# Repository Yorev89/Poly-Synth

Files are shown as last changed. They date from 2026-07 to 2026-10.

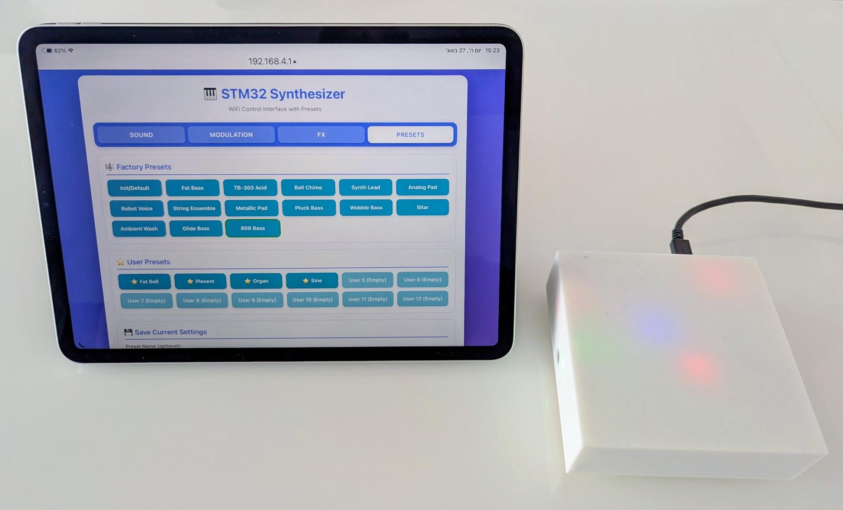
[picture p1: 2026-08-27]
docs/images/Synth and Tablet.jpg

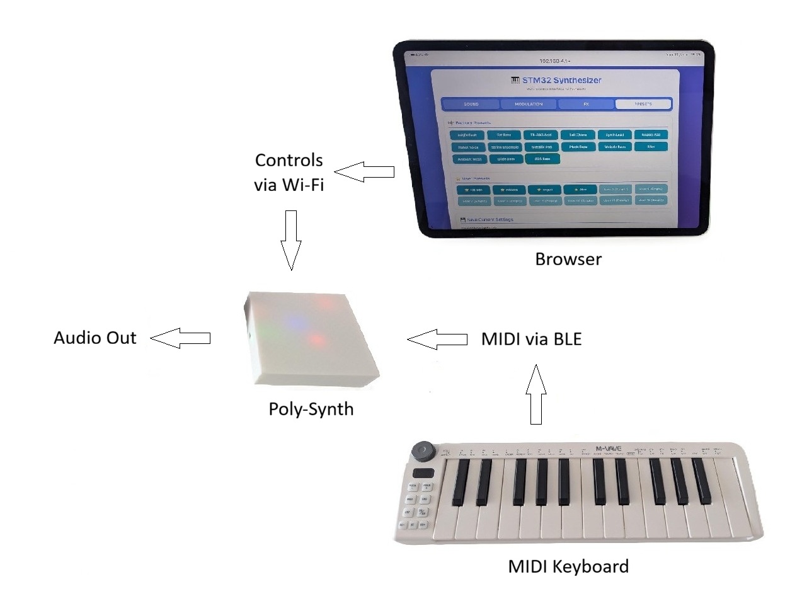
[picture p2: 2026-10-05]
docs/images/MIDI_and_Control.jpg

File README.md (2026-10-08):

# Poly-Synth — DIY Polyphonic Synthesizer
**Live site:** [yorev89.github.io/Poly-Synth](https://yorev89.github.io/Poly-Synth)

A homebrew polyphonic synthesizer built from scratch, based on a 
three-MCU architecture. This repository contains all firmware files 
and hardware resources.

## Architecture

| MCU | Role |
|---|---|
| STM32F411 | Synthesis engine, I2S audio (DIN MIDI input wired, currently disabled) |
| ESP32 #1  | Web UI, WiFi access point |
| ESP32 #2  | BLE MIDI keyboard interface |

## Features

### Synthesis Engine
- 8-voice polyphony with envelope-based voice scaling and click-free voice stealing
- Dual oscillators (Osc1 + Osc2) with 4 waveforms each: Sine, Sawtooth, Square, Triangle
- Sub oscillator: Sine or Square, selectable at -1 or -2 octaves
- White noise generator with adjustable level
- Ring modulator — continuously blendable from additive mix to full ring modulation
- Osc2 independent level and detune control (0–100 cents)
- Portamento (legato glide) with adjustable time (0–500ms), triggers on legato playing only
- Pitch bend with adjustable range

### Envelopes
- Volume ADSR: Attack 1–1000ms, Decay 1–1000ms, Sustain 0–100%, Release 1–3000ms
- Filter ADSR envelope with adjustable amount (0–100%), independently enable/disable

### Filter
- Global resonant low-pass: 2-pole (12 dB/octave) state-variable filter
- Cutoff and resonance controls; filter envelope and LFO modulation
  (sweeps from 60 Hz up to 18 kHz)

### LFO System
- Two independent LFOs
- Rate: 0.1–20 Hz each
- Waveforms: Sine, Triangle, Square, Sawtooth Up, Sawtooth Down
- Modulation targets per LFO: pitch (vibrato), filter cutoff, amplitude (tremolo), Osc2 detune

### Effects
- Stereo output: each voice is panned by pitch (low notes left, high right)
- Stereo delay (10–400ms) with time, feedback, and mix controls
- 4 delay presets (Slapback, Short, Medium, Rhythmic) plus Off; ping-pong mode
- Modulated stereo chorus

### Presets
- 15 factory presets: Init/Default, Fat Bass, TB-303 Acid, Bell Chime, Synth Lead,
  Analog Pad, Robot Voice, String Ensemble, Metallic Pad, Pluck Bass, Wobble Bass,
  Sitar, Ambient Wash, Glide Bass, 808 Bass
- 12 user-saveable preset slots (stored in ESP32 non-volatile memory)

### Connectivity & Control
- WiFi access point — no app required, connect directly from any browser
- 4-tab web interface: Sound, Modulation, FX, Presets
- BLE MIDI keyboard interface — auto-discovers BLE MIDI devices, with preferred
  device priority and automatic fallback to any BLE MIDI device
- Web-settable volume ceiling for venue or parental control, protected by a
  4-digit passcode enforced by the web controller
- MIDI keyboard volume (CC7) respects the web-set ceiling

## Firmware

| File | Board |
|---|---|
| `stm32_Synth_Engine.ino` | STM32F411 |
| `esp32_WEB_Controller.ino` | ESP32 #1  |
| `esp32_BLE.ino` | ESP32 #2  |

All three are built with the Arduino IDE.

### Required build settings for the STM32
- Core: STM32duino (STM32 MCU based boards)
- Board: Generic STM32F4 series, **Board part number: BlackPill F411CE**
  (uses the board's 25 MHz crystal for accurate tuning)
- **Tools → Optimize: Fastest (-O3)**. This is required: with the default
  "Smallest (-Os)" the synthesis loop cannot keep up with 8 voices and
  the audio distorts.

## Status
Hardware complete and verified. Firmware is playable and in active
development. Phase 2 bug fixing is complete (tuning, CPU load, clicks,
voice stealing, pitch bend, release tails, BLE MIDI parsing, volume lock);
the freed processor time went into stereo output, a modulated chorus,
ping-pong delay, and a resonant filter. Next: anti-aliased oscillators and
exponential envelope curves.

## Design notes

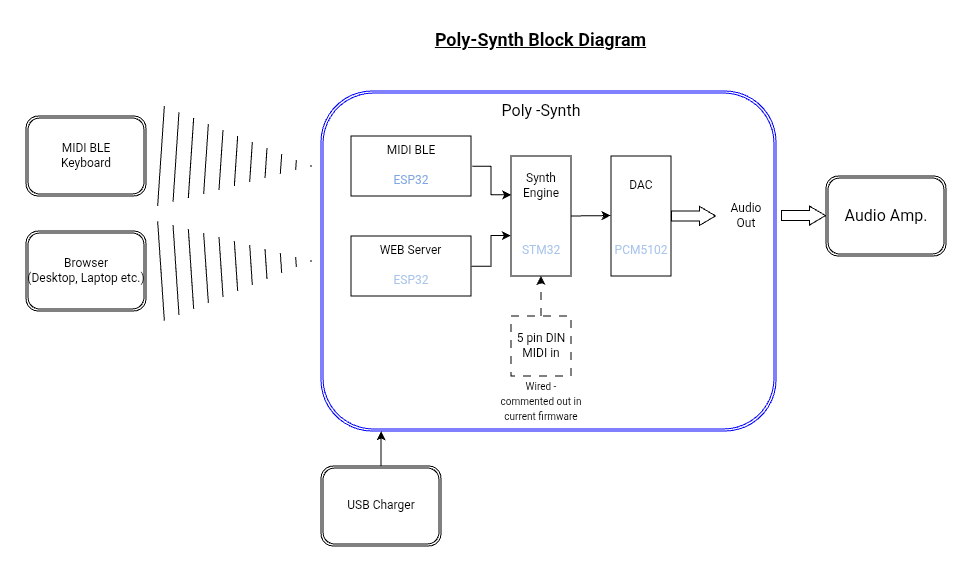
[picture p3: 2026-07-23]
Hardware/Schematics/Poly-Synth Block Diagram.png

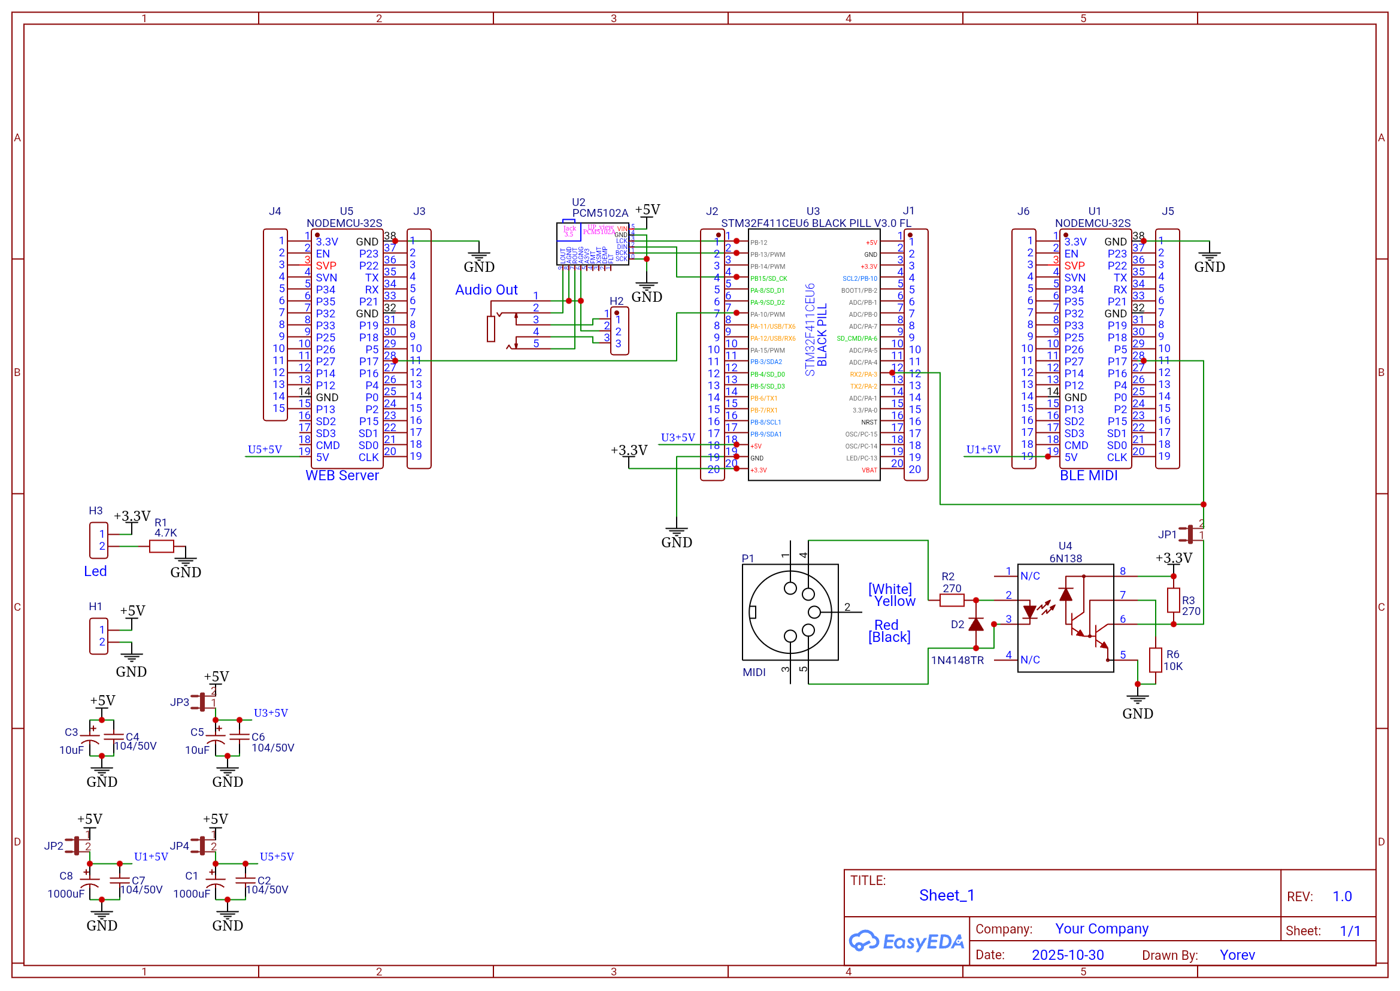
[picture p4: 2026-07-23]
Hardware/Schematics/Poly-Synth Schematic.png

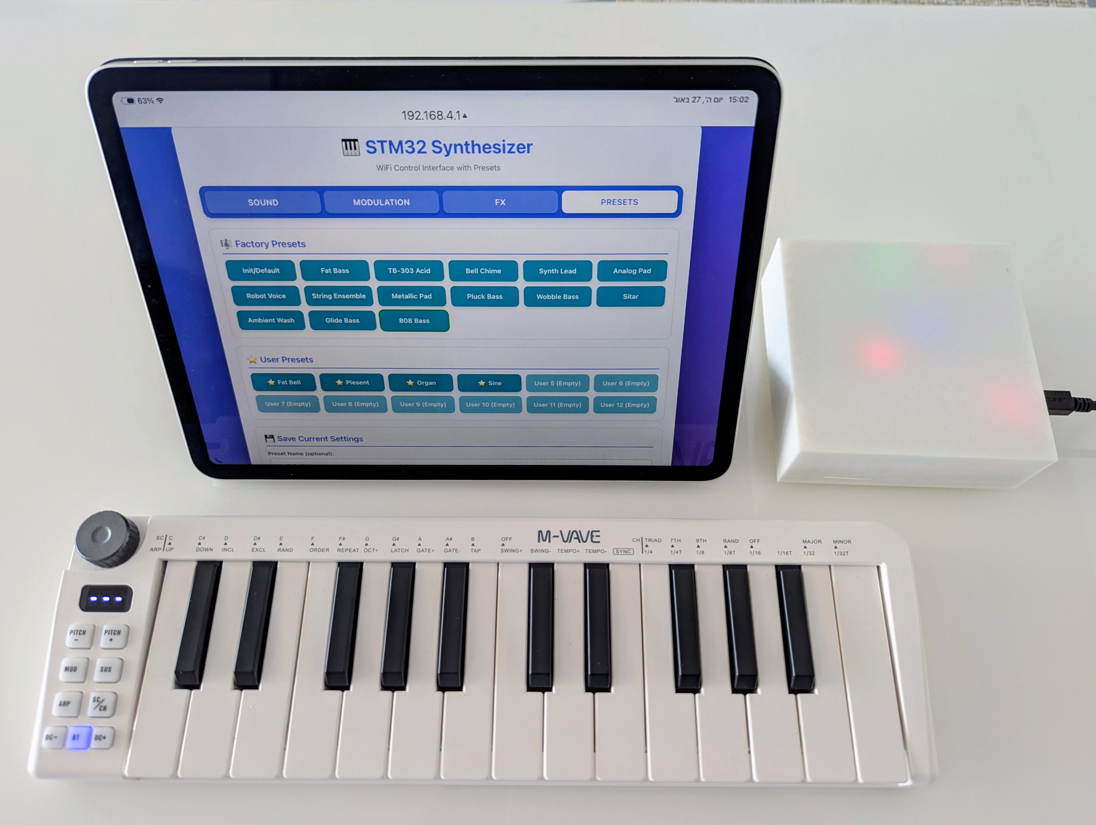
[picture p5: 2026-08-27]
docs/images/Synth.jpg

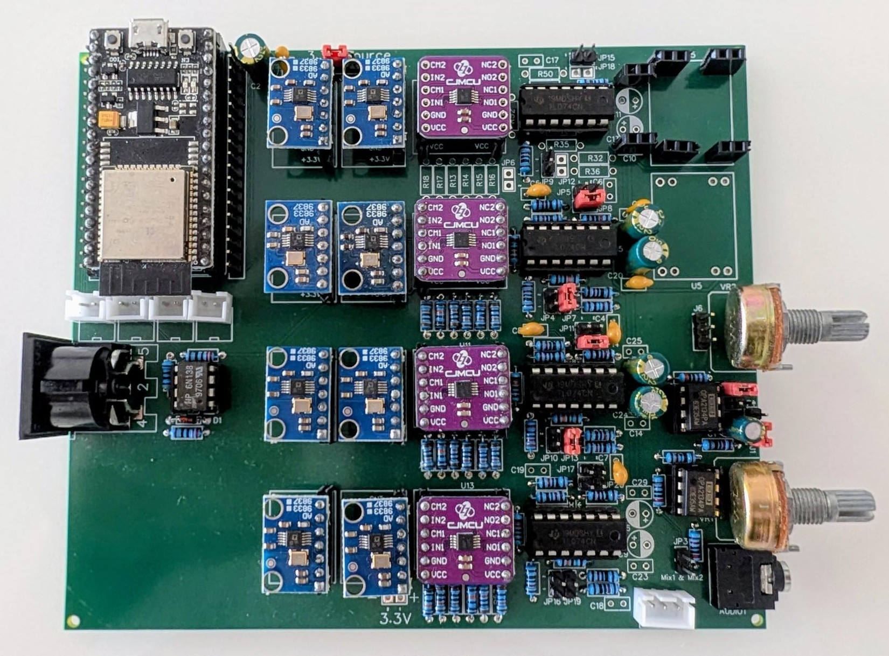
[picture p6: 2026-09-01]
docs/images/Analog Synth.jpg

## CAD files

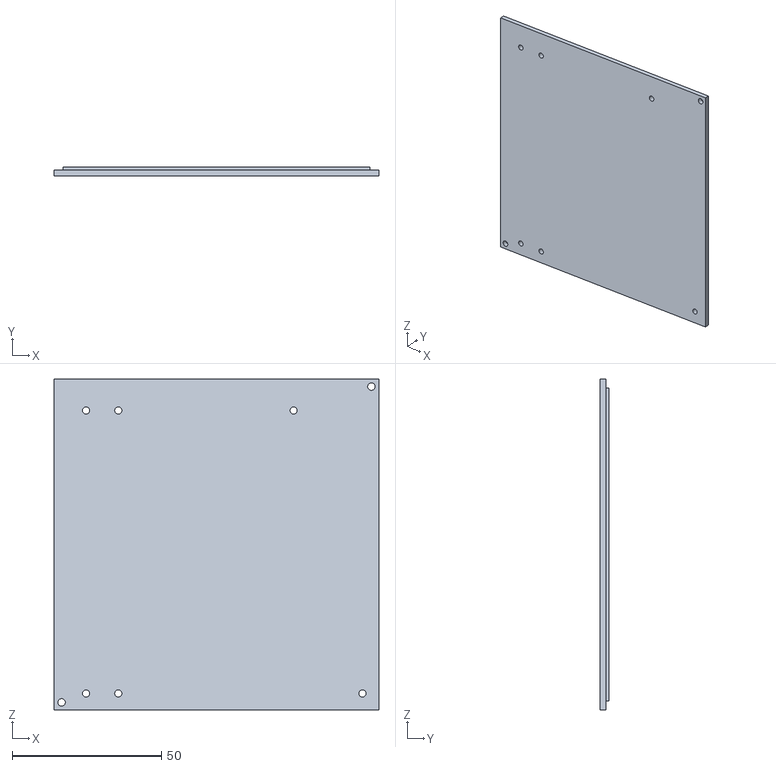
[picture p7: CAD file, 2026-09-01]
Hardware/synth-case-files/Synth Box Base.stl
109.0 x 3.00 x 111.0

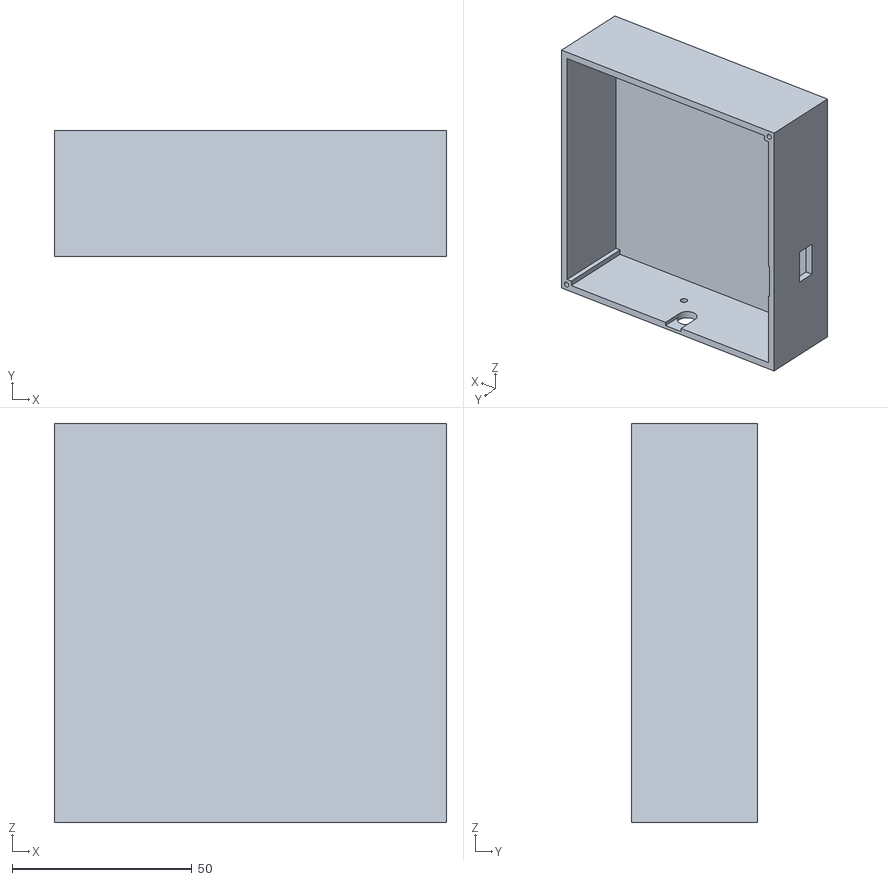
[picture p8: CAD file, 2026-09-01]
Hardware/synth-case-files/Synth Box USBC.stl
109.0 x 35.0 x 111.0

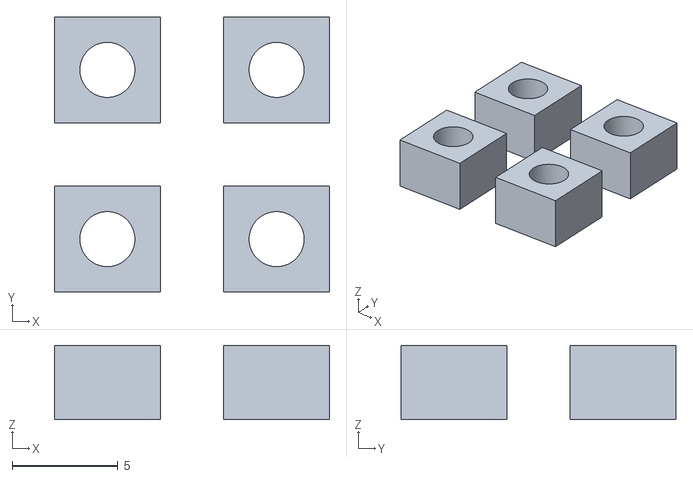
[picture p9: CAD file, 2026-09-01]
Hardware/synth-case-files/Spacers.stl
13.0 x 13.0 x 3.50

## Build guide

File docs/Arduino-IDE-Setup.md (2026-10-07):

# Arduino IDE Setup Guide

## Required Board Libraries

Install these via Arduino IDE → Board Manager:

- **ESP32** by Espressif Systems
- **STM32 MCU based boards** by STMicroelectronics

---

## STM32 Settings (F411CEU6)

**Tools menu:**

| Setting | Value |
|---|---|
| Board | STM32 MCU based boards → Generic STM32F4 Series |
| Board part number | BlackPill F411CE |
| Upload method | STM32CubeProgrammer (DFU) |
| U(S)ART support | Enabled (generic Serial) |
| USB support | CDC (generic Serial supersede U(S)ART) |
| Optimize | Fastest (-O3) |
| Port | Whichever COM/dev port appears when connected |

**Entering DFU mode (USB upload, no ST-Link):**

1. Hold BOOT0 button
2. Press and release RESET
3. Release BOOT0
4. Upload from IDE

> If using an ST-Link, no button sequence needed — connect and upload via SWD.

---

## ESP32 Settings (NodeMCU-32S)

**Tools menu:**

| Setting | Value |
|---|---|
| Board | ESP32 Arduino → ESP32 Dev Module |
| Upload Speed | 921600 |
| CPU Frequency | 240MHz (WiFi/BT) |
| Flash Frequency | 80MHz |
| Flash Mode | QIO |
| Flash Size | 4MB (32Mb) |
| Partition Scheme | Default 4MB with spiffs |
| Core Debug Level | None |
| PSRAM | Disabled |
| Port | Whichever COM/dev port appears when connected |

> NodeMCU-32S has auto-reset built in — no button sequence needed, just hit Upload.

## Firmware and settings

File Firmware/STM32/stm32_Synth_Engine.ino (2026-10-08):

/*
 * STM32F411CEU6 Polyphonic Synthesizer - Poly-Synth synthesis engine
 * https://github.com/Yorev89/Poly-Synth
 *
 * Features:
 * - 8-voice polyphony with adaptive voice scaling and click-free voice stealing
 * - Dual oscillators + sub oscillator (4 waveforms each), ring modulator
 * - ADSR amplitude envelope per voice + filter envelope
 * - Global resonant 2-pole (12 dB/oct) state-variable low-pass, LFO + envelope
 * - Stereo voice panning by pitch; delay (10-400 ms, presets, ping-pong mode);
 *   modulated stereo chorus (10 ms +/- 2.5 ms, 0.5 Hz, L/R 90 deg apart)
 * - 2x LFO (pitch, filter, amplitude, detune modulation)
 * - 15 factory presets + 12 user preset slots (stored on ESP32 #1)
 * - I2S sample rate computed at boot; tuning compensated to the real rate
 * - Voice gain scaled by summed envelope levels (smooth chords and release tails)
 *
 * Hardware:
 * - STM32F411CEU6 (WeAct Black Pill V3.1), 25 MHz HSE, 96 MHz core
 * - PCM5102A DAC via I2S (PB12=WS, PB13=BCK, PB15=DIN)
 * - ESP32 #1 (web controller, Wi-Fi AP) -> UART RX on PA10 (WebSerial)
 * - ESP32 #2 (BLE MIDI receiver)        -> UART RX on PA3, TX on PA2 (ESP32Serial)
 * - 5-pin DIN MIDI input: wired, but disabled - its UART pin (PA10) now serves ESP32 #1
 *
 * MIDI flow:
 * BLE MIDI keyboard -> ESP32 #2 -> UART -> STM32
 * Commands: NOTE,<note>,<velocity> | NOTEOFF,<note> | PITCHBEND,<lsb>,<msb> | CC,<num>,<val>
 *
 * Build: Arduino IDE, STM32 core, Board part number: BlackPill F411CE
 *        (uses the 25 MHz crystal), Tools -> Optimize -> Fastest (-O3) REQUIRED
 * (with the default -Os the render loop misses its deadline and audio distorts)
 */

#include <Arduino.h>

#define TARGET_SAMPLE_RATE 44100.0f
// Real output sample rate, set by configureI2SClock() at the start of setup().
// All pitch/time calculations use this value, so tuning stays correct even if
// the clock tree can't produce exactly 44100 Hz.
float SAMPLE_RATE = TARGET_SAMPLE_RATE;
uint16_t i2sPrescaler = 0;  // Value for SPI2->I2SPR: I2SDIV | (ODD << 8)
// DIAGNOSTICS (temporary): render timing
uint32_t diagMaxRenderCycles = 0;
uint32_t diagMissedBuffers = 0;
volatile uint32_t diagHalfStamp = 0, diagFullStamp = 0;  // DWT time of DMA interrupt
uint32_t diagMaxLatencyCycles = 0;  // interrupt -> render finished
uint32_t diagLateBuffers = 0;       // renders that finished after their deadline
#define AUDIO_BUFFER_SIZE 512
#define WAVE_TABLE_SIZE 256
#define MAX_VOICES 8
#define MIDI_BAUD_RATE 31250

#define MIDI_NOTE_OFF 0x80
#define MIDI_NOTE_ON 0x90
#define MIDI_CONTROL_CHANGE 0xB0
#define MIDI_PITCH_BEND 0xE0

enum WaveType { WAVE_SINE, WAVE_SAW, WAVE_SQUARE, WAVE_TRIANGLE };
enum EnvStage { ENV_IDLE, ENV_ATTACK, ENV_DECAY, ENV_SUSTAIN, ENV_RELEASE };

int16_t sineTable[WAVE_TABLE_SIZE];
int16_t sawTable[WAVE_TABLE_SIZE];
int16_t squareTable[WAVE_TABLE_SIZE];
int16_t triangleTable[WAVE_TABLE_SIZE];

int16_t audioBuffer[AUDIO_BUFFER_SIZE];
DMA_HandleTypeDef hdma_spi2_tx;
volatile uint32_t halfComplete = 0;
volatile uint32_t fullComplete = 0;

// HardwareSerial MidiSerial(PA10, PA9);  // COMMENTED OUT - PA10 used by WebSerial
HardwareSerial ESP32Serial(PA3, PA2);
HardwareSerial WebSerial(PA10, PA9);  // ESP32 #1 Web Control
uint8_t midiChannel = 0xFF;

struct Oscillator {
  uint32_t phase;
  uint32_t phaseInc;
  WaveType waveType;
  float detune;
};

struct Envelope {
  EnvStage stage;
  float level;
  float attackRate;
  float decayRate;
  float sustainLevel;
  float releaseRate;
};

struct Voice {
  bool active;
  uint8_t note;
  Oscillator osc1;
  Oscillator osc2;
  Oscillator sub;
  Envelope env;
  Envelope filterEnv;
  float velocity;
  float panL, panR;          // Stereo gains, set from the note's pitch at note-on
  unsigned long noteOnTime;
  // Portamento (cheap phaseInc-based approach)
  bool portaActive;
  float portaRate;           // Multiply phaseInc by this each sample
  uint32_t portaTargetInc1;  // Target phaseInc for osc1
  uint32_t portaTargetInc2;  // Target phaseInc for osc2
  uint32_t portaTargetSubInc;// Target phaseInc for sub
  // Float accumulators - avoid uint32_t truncation during slow glides
  float portaInc1f;
  float portaInc2f;
  float portaSubIncf;
};

Voice voices[MAX_VOICES];

// Global resonant low-pass filter: 2-pole (12 dB/octave) state-variable filter
// in the trapezoidal / zero-delay-feedback form (Andrew Simper, Cytomic),
// which stays stable and in tune up to the highest cutoff settings.
// (Replaces the one-pole 6 dB/octave filter that had no resonance.)
struct GlobalFilter {
  float a1, a2, a3;      // coefficients for the current cutoff / resonance
  float ic1L, ic2L;      // left channel integrator states
  float ic1R, ic2R;      // right channel integrator states
} globalFilter;
float filterResonance = 0.0f;  // 0..1 (0 = flat Butterworth, 1 = Q 10, strong squelch)

// ==================== SYNTH PARAMETERS ====================

float osc1Detune = 0.0;
float osc2Detune = 7.0;
float osc2Level = 0.7;  // Adjustable via WiFi
WaveType osc1Wave = WAVE_SAW;
WaveType osc2Wave = WAVE_SAW;

// Sub oscillator
float subLevel = 0.0;      // 0-100% (default OFF)
int subOctave = 1;         // 1 = -1 octave, 2 = -2 octaves
WaveType subWave = WAVE_SINE;  // SINE or SQUARE (classic choices)

// Ring Modulator
float ringModAmount = 0.0;  // 0-100% (0=additive, 100=full ring mod)

// Portamento
bool portamentoEnabled = false;
float portamentoTime = 0.1;   // 0-2 seconds
float lastPlayedFreq = 0.0;   // Source frequency for glide

// Noise generator
float noiseLevel = 0.0;    // 0-100% (default OFF)

// ADSR - now adjustable via WiFi!
float attackTime = 0.005;    // 1-1000 ms
float decayTime = 0.05;      // 1-1000 ms
float sustainLevel = 0.7;    // 0-100%
float releaseTime = 0.05;    // 1-3000 ms

// Filter Envelope
bool filterEnvEnabled = false;
float filterEnvAttack = 0.005;    // 1-1000 ms
float filterEnvDecay = 0.05;      // 1-1000 ms
float filterEnvSustain = 0.5;     // 0-100%
float filterEnvRelease = 0.05;    // 1-3000 ms
float filterEnvAmount = 0.5;      // 0-100% - how much envelope affects filter

float filterCutoff = 5000.0;

// LFO System
enum LFOWaveType { LFO_SINE, LFO_TRIANGLE, LFO_SQUARE, LFO_SAW_UP, LFO_SAW_DOWN };
struct LFO {
  uint32_t phase;
  uint32_t phaseInc;
  LFOWaveType waveType;
  float rate;  // Hz (0.1 - 20 Hz)
  
  // Modulation depths (0.0 - 1.0)
  float pitchDepth;      // Vibrato (0-100 cents)
  float filterDepth;     // Filter mod (0-3000 Hz)
  float ampDepth;        // Tremolo
  float osc2DetuneDepth; // Osc2 detune mod (0-50 cents)
} lfo1, lfo2;  // Two independent LFOs!

bool lfo1Enabled = false;
bool lfo2Enabled = false;

// 400 ms at 44.1 kHz, stored as int16 (same RAM as the old 200 ms float buffers).
// Range +/-2.0 maps to the full int16 range (DELAY_SCALE = 16384).
#define DELAY_BUFFER_SIZE 17640
#define DELAY_SCALE 16384.0f
int16_t delayBufferL[DELAY_BUFFER_SIZE];
int16_t delayBufferR[DELAY_BUFFER_SIZE];
int delayWritePos = 0;
float delayTime = 0.0;       // 0 seconds (off)
float delayFeedback = 0.0;
float delayMix = 0.0;
int delayPreset = 0;
bool delayPingPong = false;  // ping-pong mode: echoes alternate left / right
int feedbackPreset = 1;


#define CHORUS_BUFFER_SIZE 1323
float chorusBufferL[CHORUS_BUFFER_SIZE];
float chorusBufferR[CHORUS_BUFFER_SIZE];
int chorusWritePos = 0;
float chorusMix = 0.6;
bool chorusEnabled = false;

// Modulated stereo chorus: one delay line per channel, read at a delay that a
// slow LFO sweeps around CHORUS_BASE_MS; left and right LFOs are a quarter
// cycle apart for width. (Replaces the old static 4-tap comb filter.)
#define CHORUS_BASE_MS   10.0f   // centre delay
#define CHORUS_DEPTH_MS   2.5f   // sweep +/- this much
#define CHORUS_RATE_HZ    0.5f   // LFO rate
float chorusLfoPhase = 0.0f;     // 0..1

float masterVolume = 1.0;  // Maximum (was 0.7 = +43% gain)
float volumeCeiling = 1.0;  // 0-1: Web-locked maximum volume (parent control)
float keyboardVolumeCC = 1.0;  // 0-1: MIDI keyboard's volume knob position
float pitchBendAmount = 0.0;
float pitchBendRange = 2.0;

// ==========================================================

const char* getWaveName(WaveType wave) {
  switch(wave) {
    case WAVE_SINE: return "SINE";
    case WAVE_SAW: return "SAW";
    case WAVE_SQUARE: return "SQUARE";
    case WAVE_TRIANGLE: return "TRIANGLE";
    default: return "UNKNOWN";
  }
}

// ==================== I2S CLOCK CONFIGURATION ====================
// Searches PLLI2S M/N/R and I2SDIV/ODD for the rate closest to targetRate,
// programs PLLI2S, and returns the sample rate actually produced.
// I2S mode: 16-bit data, 16-bit channel (32 bits per stereo frame), no MCLK:
//   Fs = I2SCLK / (32 * (2*I2SDIV + ODD))
// Limits (RM0383 / F411 datasheet): PLL input 0.95-2.1 MHz, VCO 100-432 MHz,
// I2SCLK <= 192 MHz, N 50-432, R 2-7, I2SDIV 2-255.
float configureI2SClock(float targetRate) {
  bool useHSE = (RCC->PLLCFGR & RCC_PLLCFGR_PLLSRC) != 0;  // PLLI2S shares the PLL source
  float srcHz = useHSE ? (float)HSE_VALUE : (float)HSI_VALUE;

#ifdef RCC_PLLI2SCFGR_PLLI2SM
  const uint32_t mMin = 2, mMax = 63;   // F411: PLLI2S has its own input divider
#else
  uint32_t mFixed = RCC->PLLCFGR & RCC_PLLCFGR_PLLM;  // otherwise shares main PLLM
  const uint32_t mMin = mFixed, mMax = mFixed;
#endif

  float bestErr = 1e12f, bestRate = 0.0f;
  uint32_t bestM = 0, bestN = 0, bestR = 0, bestK = 0;

  for (uint32_t m = mMin; m <= mMax; m++) {
    float pllIn = srcHz / m;
    if (pllIn < 0.95e6f || pllIn > 2.1e6f) continue;
    for (uint32_t n = 50; n <= 432; n++) {
      float vco = pllIn * n;
      if (vco < 100e6f || vco > 432e6f) continue;
      for (uint32_t r = 2; r <= 7; r++) {
        float i2sclk = vco / r;
        if (i2sclk > 192e6f) continue;
        uint32_t k = (uint32_t)(i2sclk / (32.0f * targetRate) + 0.5f);  // k = 2*DIV + ODD
        if (k < 4 || k > 511) continue;
        float rate = i2sclk / (32.0f * k);
        float err = fabsf(rate - targetRate);
        if (err < bestErr) {
          bestErr = err; bestRate = rate;
          bestM = m; bestN = n; bestR = r; bestK = k;
        }
      }
    }
  }

  // Program PLLI2S (must be off while changing it)
  RCC->CR &= ~RCC_CR_PLLI2SON;
  while (RCC->CR & RCC_CR_PLLI2SRDY);
  uint32_t cfg = (bestN << RCC_PLLI2SCFGR_PLLI2SN_Pos) |
                 (bestR << RCC_PLLI2SCFGR_PLLI2SR_Pos);
#ifdef RCC_PLLI2SCFGR_PLLI2SM
  cfg |= (bestM << RCC_PLLI2SCFGR_PLLI2SM_Pos);
#endif
  RCC->PLLI2SCFGR = cfg;
  RCC->CR |= RCC_CR_PLLI2SON;
  while (!(RCC->CR & RCC_CR_PLLI2SRDY));

  i2sPrescaler = (uint16_t)((bestK >> 1) | ((bestK & 1) << 8));

  Serial.print("I2S clock: src=");   Serial.print(useHSE ? "HSE " : "HSI ");
  Serial.print(srcHz / 1e6f, 3);     Serial.print(" MHz  M=");  Serial.print(bestM);
  Serial.print(" N=");  Serial.print(bestN);
  Serial.print(" R=");  Serial.print(bestR);
  Serial.print(" DIV="); Serial.print(bestK >> 1);
  Serial.print(" ODD="); Serial.println(bestK & 1);
  Serial.print("Sample rate: "); Serial.print(bestRate, 2);
  Serial.print(" Hz (error "); Serial.print(1200.0f * log2f(bestRate / targetRate), 2);
  Serial.println(" cents, compensated)");

  return bestRate;
}

void generateWavetables() {
  for (int i = 0; i < WAVE_TABLE_SIZE; i++) {
    float phase = (float)i / WAVE_TABLE_SIZE;
    sineTable[i] = (int16_t)(sin(2.0 * PI * phase) * 32767);
    sawTable[i] = (int16_t)((2.0 * phase - 1.0) * 32767);
    squareTable[i] = (phase < 0.5) ? 32767 : -32767;
    triangleTable[i] = (int16_t)((phase < 0.5 ? (4.0 * phase - 1.0) : (3.0 - 4.0 * phase)) * 32767);
  }
}

void setDelayPreset(int preset) {
  switch(preset) {
    case 0:
      delayMix = 0.0;
      delayTime = 0.0;       // OFF = no delay time
      delayFeedback = 0.0;
      Serial.println("Delay: OFF");
      break;
    case 1:
      delayTime = 0.08;
      delayFeedback = 0.0;
      delayMix = 0.4;
      Serial.println("Delay: SLAPBACK");
      break;
    case 2:
      delayTime = 0.15;
      delayFeedback = 0.6;
      delayMix = 0.4;
      Serial.println("Delay: SHORT");
      break;
    case 3:
      delayTime = 0.2;
      delayFeedback = 0.5;
      delayMix = 0.35;
      Serial.println("Delay: MEDIUM");
      break;
    case 4:
      delayTime = 0.12;
      delayFeedback = 0.5;
      delayMix = 0.35;
      Serial.println("Delay: RHYTHMIC");
      break;
  }
}

void setFeedbackPreset(int preset) {
  switch(preset) {
    case 0:
      delayFeedback = 0.2;
      Serial.println("Feedback: LOW");
      break;
    case 1:
      delayFeedback = 0.5;
      Serial.println("Feedback: MEDIUM");
      break;
    case 2:
      delayFeedback = 0.8;
      Serial.println("Feedback: HIGH");
      break;
  }
}

// Phase increment with LFO modulation; unmodulated increments stay exact
inline uint32_t modInc(uint32_t inc, float mult, bool on) {
  return on ? (uint32_t)(inc * mult) : inc;
}

// Returns the wavetable for a waveform (chosen once per buffer instead of a
// switch on every sample)
inline const int16_t* waveTablePtr(WaveType type) {
  switch(type) {
    case WAVE_SAW:      return sawTable;
    case WAVE_SQUARE:   return squareTable;
    case WAVE_TRIANGLE: return triangleTable;
    default:            return sineTable;
  }
}

inline int16_t getWaveSample(WaveType type, uint32_t phase) {
  uint32_t index = (phase >> 24) & 0xFF;
  switch(type) {
    case WAVE_SINE: return sineTable[index];
    case WAVE_SAW: return sawTable[index];
    case WAVE_SQUARE: return squareTable[index];
    case WAVE_TRIANGLE: return triangleTable[index];
    default: return 0;
  }
}

float noteToFreq(uint8_t note) {
  return 440.0 * pow(2.0, (note - 69) / 12.0);
}

uint32_t freqToPhaseInc(float freq, float detune) {
  float detuneRatio = pow(2.0, detune / 1200.0);
  float actualFreq = freq * detuneRatio;
  return (uint32_t)((actualFreq * 4294967296.0) / SAMPLE_RATE);
}

void updateLFORate(int lfoNum, float hz) {
  if (hz < 0.1) hz = 0.1;
  if (hz > 20.0) hz = 20.0;
  
  if (lfoNum == 1) {
    lfo1.rate = hz;
    lfo1.phaseInc = (uint32_t)((hz * 4294967296.0) / SAMPLE_RATE);
  } else if (lfoNum == 2) {
    lfo2.rate = hz;
    lfo2.phaseInc = (uint32_t)((hz * 4294967296.0) / SAMPLE_RATE);
  }
}

// Simple white noise generator using linear congruential generator (LCG)
inline int16_t generateNoise() {
  static uint32_t noiseSeed = 12345;  // Starting seed
  noiseSeed = (noiseSeed * 1103515245 + 12345) & 0x7fffffff;  // LCG algorithm
  return (int16_t)((noiseSeed >> 16) - 16384);  // Convert to -16384 to +16384 range
}

void initVoice(Voice* v) {
  v->active = false;
  v->note = 0;
  v->velocity = 0;
  v->panL = 1.0f;
  v->panR = 1.0f;
  v->osc1.phase = 0;
  v->osc2.phase = 0;
  v->env.stage = ENV_IDLE;
  v->env.level = 0;
}

void updateGlobalFilter(float cutoffHz) {
  if (cutoffHz < 20.0f) cutoffHz = 20.0f;
  if (cutoffHz > 18000.0f) cutoffHz = 18000.0f;
  float fc = cutoffHz / SAMPLE_RATE;
  if (fc > 0.45f) fc = 0.45f;
  
  float g = tanf((float)PI * fc);                   // pre-warped cutoff
  float k = 1.4142f - 1.3142f * filterResonance;    // damping: 1.414 (Q 0.71) .. 0.1 (Q 10)
  globalFilter.a1 = 1.0f / (1.0f + g * (g + k));
  globalFilter.a2 = g * globalFilter.a1;
  globalFilter.a3 = g * globalFilter.a2;
}

void resetGlobalFilter() {
  globalFilter.ic1L = globalFilter.ic2L = 0.0f;
  globalFilter.ic1R = globalFilter.ic2R = 0.0f;
}

// Bend ratio currently applied to the voices (1.0 = no bend)
float pitchBendRatioApplied = 1.0f;

// Applies the current pitchBendAmount to every active voice: osc1, osc2 AND the
// sub oscillator (the sub used to stay unbent and drift out of tune). A voice
// that is mid-glide keeps gliding: its current pitch and its target are both
// shifted by the bend change (bend used to be overwritten by the glide).
void applyPitchBend() {
  float ratio = powf(2.0f, pitchBendAmount / 12.0f);
  float change = ratio / pitchBendRatioApplied;
  pitchBendRatioApplied = ratio;
  
  for (int v = 0; v < MAX_VOICES; v++) {
    if (!voices[v].active) continue;
    float freq = noteToFreq(voices[v].note) * ratio;
    uint32_t inc1   = freqToPhaseInc(freq, osc1Detune);
    uint32_t inc2   = freqToPhaseInc(freq, osc2Detune);
    uint32_t incSub = freqToPhaseInc(freq / (float)(1 << subOctave), 0.0);
    
    if (voices[v].portaActive) {
      voices[v].portaTargetInc1   = inc1;
      voices[v].portaTargetInc2   = inc2;
      voices[v].portaTargetSubInc = incSub;
      voices[v].portaInc1f   *= change;
      voices[v].portaInc2f   *= change;
      voices[v].portaSubIncf *= change;
    } else {
      voices[v].osc1.phaseInc = inc1;
      voices[v].osc2.phaseInc = inc2;
      voices[v].sub.phaseInc  = incSub;
    }
  }
}

// ==================== STEREO VOICE PANNING ====================
// Each note is placed in the stereo field by pitch, like a piano seen from the
// player's seat: low notes slightly left, high notes slightly right, middle C
// centred. PAN_WIDTH 0 = mono, 1 = full left/right at the keyboard extremes.
#define PAN_WIDTH 0.5f
void setVoicePan(Voice* v, uint8_t note) {
  float p = ((float)note - 60.0f) / 30.0f;      // -1 at C2-ish ... +1 at F#6-ish
  if (p >  1.0f) p =  1.0f;
  if (p < -1.0f) p = -1.0f;
  p *= PAN_WIDTH;
  // Constant-power pan law, scaled so a centred note keeps its old level (1.0)
  float theta = (p + 1.0f) * 0.25f * (float)PI;  // 0 .. PI/2
  v->panL = 1.41421356f * cosf(theta);
  v->panR = 1.41421356f * sinf(theta);
}
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
void loop() {
  processMIDI();  // 5-pin MIDI (commented out inside)
  processESP32Commands();  // ESP32 #2 BLE MIDI on PA3
  processWebControl();  // ESP32 #1 Web Control on PA10
  
  static uint32_t lastHalf = 0;
  static uint32_t lastFull = 0;
  
  if (halfComplete != lastHalf) {
    if (halfComplete - lastHalf > 1) diagMissedBuffers += halfComplete - lastHalf - 1;
    uint32_t t0 = DWT->CYCCNT;
    renderAudio(audioBuffer, 0, AUDIO_BUFFER_SIZE / 2);
    uint32_t dt = DWT->CYCCNT - t0;
    if (dt > diagMaxRenderCycles) diagMaxRenderCycles = dt;
    uint32_t lat = DWT->CYCCNT - diagHalfStamp;
    if (lat > diagMaxLatencyCycles) diagMaxLatencyCycles = lat;
    if (lat > (uint32_t)((float)SystemCoreClock * (AUDIO_BUFFER_SIZE / 4) / SAMPLE_RATE)) diagLateBuffers++;
    lastHalf = halfComplete;
  }
  
  if (fullComplete != lastFull) {
    if (fullComplete - lastFull > 1) diagMissedBuffers += fullComplete - lastFull - 1;
    uint32_t t0 = DWT->CYCCNT;
    renderAudio(audioBuffer, AUDIO_BUFFER_SIZE / 2, AUDIO_BUFFER_SIZE / 2);
    uint32_t dt = DWT->CYCCNT - t0;
    if (dt > diagMaxRenderCycles) diagMaxRenderCycles = dt;
    uint32_t lat = DWT->CYCCNT - diagFullStamp;
    if (lat > diagMaxLatencyCycles) diagMaxLatencyCycles = lat;
    if (lat > (uint32_t)((float)SystemCoreClock * (AUDIO_BUFFER_SIZE / 4) / SAMPLE_RATE)) diagLateBuffers++;
    lastFull = fullComplete;
  }
  
  static unsigned long lastBlink = 0;
  if (millis() - lastBlink > 1000) {
    lastBlink = millis();
    digitalWrite(PC13, !digitalRead(PC13));
    
    // DIAGNOSTICS (temporary): worst-case render time vs. half-buffer budget
    {
      float budgetUs = (AUDIO_BUFFER_SIZE / 4) * 1e6f / SAMPLE_RATE;  // 128 frames
      float maxUs = diagMaxRenderCycles * 1e6f / SystemCoreClock;
      int voicesOn = 0;
      for (int i = 0; i < MAX_VOICES; i++) if (voices[i].active) voicesOn++;
      Serial.print("Render max "); Serial.print(maxUs, 0);
      Serial.print(" us / budget "); Serial.print(budgetUs, 0);
      Serial.print(" us ("); Serial.print(100.0f * maxUs / budgetUs, 0);
      Serial.print("%)  deadline used max ");
      Serial.print(100.0f * (diagMaxLatencyCycles * 1e6f / SystemCoreClock) / budgetUs, 0);
      Serial.print("%  late="); Serial.print(diagLateBuffers);
      Serial.print("  missed="); Serial.print(diagMissedBuffers);
      Serial.print("  voices="); Serial.println(voicesOn);
      diagMaxRenderCycles = 0;
      diagMaxLatencyCycles = 0;
    }
    
    // (30-second stuck-note watchdog removed: it also cut legitimately held
    //  notes. Stuck notes are now prevented at the source - fixed BLE parser,
    //  non-blocking serial reader, "all notes off" on BLE disconnect - and the
    //  web page's All Notes Off button remains as the manual panic.)
  }
  
}

extern "C" void DMA1_Stream4_IRQHandler(void) {
  if (__HAL_DMA_GET_FLAG(&hdma_spi2_tx, DMA_FLAG_HTIF0_4)) {
    __HAL_DMA_CLEAR_FLAG(&hdma_spi2_tx, DMA_FLAG_HTIF0_4);
    diagHalfStamp = DWT->CYCCNT;
    halfComplete++;
  }
  
  if (__HAL_DMA_GET_FLAG(&hdma_spi2_tx, DMA_FLAG_TCIF0_4)) {
    __HAL_DMA_CLEAR_FLAG(&hdma_spi2_tx, DMA_FLAG_TCIF0_4);
    diagFullStamp = DWT->CYCCNT;
    fullComplete++;
  }
}

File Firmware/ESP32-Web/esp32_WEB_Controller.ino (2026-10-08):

/*
 * ESP32 #1 - Wi-Fi Web Controller for the Poly-Synth
 * https://github.com/Yorev89/Poly-Synth
 *
 * Features:
 * - Wi-Fi access point serving the full web interface
 * - 4-screen tabbed interface (Sound, Modulation, FX, Presets)
 * - 15 factory presets + 12 user preset slots (stored in ESP32 flash, Preferences)
 * - On-screen keyboard page
 * - Volume ceiling protected by a 4-digit passcode, enforced by the server
 *   (5-minute unlock window)
 *
 * Hardware connections:
 * - GPIO17 (TX) -> STM32 PA10 (USART1 RX)
 * - GND -> GND (required)
 * - PA10 was the 5-pin DIN MIDI input; the DIN circuit must stay disconnected
 *
 * Wi-Fi:
 * - SSID: STM32_Synth   Password: synth2024   IP: 192.168.4.1
 *
 * UART protocol (one-way, 115200 baud, one command per line):
 * - PARAM,<name>,<value> | CC,<num>,<value> | NOTE,<note>,<velocity> | NOTEOFF,<note>
 */

#include <WiFi.h>
#include <WebServer.h>
#include <ESPmDNS.h>
#include <Preferences.h>

const char* ssid = "STM32_Synth";
const char* password = "synth2024";

// UART Configuration
#define UART_RX_PIN 16  // Not physically connected, but ESP32 needs a valid pin number
#define UART_TX_PIN 17  // GPIO17 → STM32 PA10 (UART1 RX)

#define NUM_USER_PRESETS 12  // Number of user preset slots

WebServer server(80);
Preferences preferences;  // NVS storage object

// Statistics
unsigned long commandsSent = 0;


struct SynthState {
  // Oscillators
  int osc1Wave;
  int osc2Wave;
  int osc2Detune;
  
  // Envelope
  int attack;
  int decay;
  int sustain;
  int release;
  
  // Filter
  int filterCutoff;
  
  // Effects
  int delayTime;
  int delayFeedback;
  int delayMix;
  int chorusMix;
  int delayPreset;
  
  // Master
  int volume;
} state;

// Chorus state (separate variable)
bool chorusEnabled = false;

void initState() {
  state.osc1Wave = 1;
  state.osc2Wave = 1;
  state.osc2Detune = 10;
  state.attack = 2;
  state.decay = 13;
  state.sustain = 89;
  state.release = 13;
  state.filterCutoff = 64;
  state.delayTime = 0;
  state.delayFeedback = 0;
  state.delayMix = 0;
  state.chorusMix = 76;
  state.delayPreset = 0;
  state.volume = 89;
}

// ========== UART COMMUNICATION ==========
void sendToSTM32(String cmd) {
  Serial2.println(cmd);  // Simple UART send!
  commandsSent++;
  
  Serial.print("→ ");
  Serial.println(cmd);
}


void sendCC(int cc, int value) {
  String cmd = "CC," + String(cc) + "," + String(value);
  sendToSTM32(cmd);
}

void sendParam(String param, int value) {
  String cmd = "PARAM," + param + "," + String(value);
  sendToSTM32(cmd);
}

void sendButton(int buttonNum) {
  String cmd = "BTN," + String(buttonNum);
  sendToSTM32(cmd);
}

// ========== WEB INTERFACE HANDLERS (unchanged) ==========
// ==========================================

// Synth Presets
struct Preset {
  const char* name;
  // Basic Oscillators
  int osc1Wave;
  int osc2Wave;
  int osc2Detune;
  int osc2Level;  // NEW
  // Sub Oscillator
  int subLevel;    // NEW
  int subOctave;   // NEW (1 or 2)
  int subWave;     // NEW (0=SINE, 2=SQUARE)
  // Noise Generator
  int noiseLevel;  // NEW
  // Volume ADSR
  int attack;
  int decay;
  int sustain;
  int release;
  // Filter
  int filterCutoff;
  // Filter Envelope
  bool filterEnvEnabled;  // NEW
  int filterEnvAttack;    // NEW
  int filterEnvDecay;     // NEW
  int filterEnvSustain;   // NEW
  int filterEnvRelease;   // NEW
  int filterEnvAmount;    // NEW
  // LFO1
  bool lfo1Enabled;       // NEW
  int lfo1Rate;           // NEW
  int lfo1Wave;           // NEW
  int lfo1Pitch;          // NEW
  int lfo1Filter;         // NEW
  int lfo1Amp;            // NEW
  int lfo1Detune;         // NEW
  // LFO2
  bool lfo2Enabled;       // NEW
  int lfo2Rate;           // NEW
  int lfo2Wave;           // NEW
  int lfo2Pitch;          // NEW
  int lfo2Filter;         // NEW
  int lfo2Amp;            // NEW
  int lfo2Detune;         // NEW
  // Effects
  int delayMix;
  int chorusMix;
  bool chorusEnabled;
  // Ring mod & Portamento
  int ringMod;           // 0-127
  bool portamentoOn;     // on/off
  int portamentoTime;    // 0-127
};

// Forward declarations for user preset functions
void saveUserPreset(int slot, const Preset& preset);
bool loadUserPreset(int slot, Preset& preset);
bool isUserPresetUsed(int slot);
String getUserPresetName(int slot);
void getCurrentSettings(Preset& preset);
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

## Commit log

2026-08-25 Create Arduino-IDE-Setup.md
    Add Arduino IDE setup guide
2026-09-01 Add 3D Files
    [Spacers.stl, Synth Box Base.stl, Synth Box USBC.stl]
2026-09-01 Rename Synth Board.jpg to Synth Board.jpg
